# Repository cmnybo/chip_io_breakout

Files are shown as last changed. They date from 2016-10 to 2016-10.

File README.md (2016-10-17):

# C.H.I.P. GPIO Breakout

This is a breakout that attaches to the LCD Adapter board with a 34 pin ribbon cable and IDC connectors.

## Features

* 2 I2C headers
* 6 SPI headers
* 16 pin GPIO header
* 16 pin analog header
* 12 bit 8 channel ADC (MAX11629)
* 12 bit 2 channel DAC (MAX5702)
* Buffered voltage reference output (2.048V & 2.5V)
* External reference voltage input (1.24V - 3.3V)
* Filtered analog power supply.

The original design files for this board were created in [KiCAD](http://kicad-pcb.org/). <br/>
There are PDF copies of the schematic, PCB layout, and bill of materials in the "pdf" directory.<br/>
The "gerber" directory contains all of the files needed to have some boards made.<br/>
The device tree overlay and example python program are in the "source" directory.

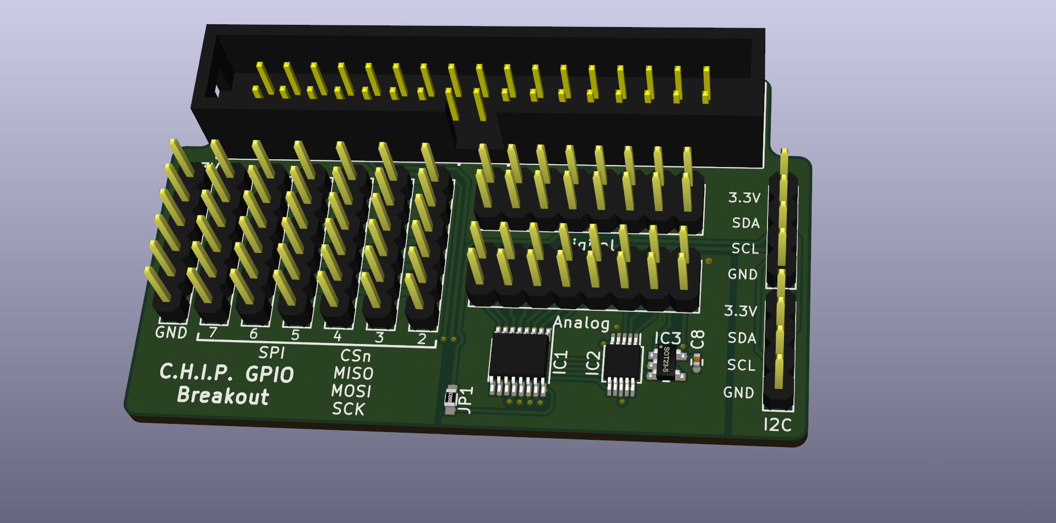
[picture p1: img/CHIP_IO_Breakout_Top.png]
3D Rendering of the breakout board


## Pinouts
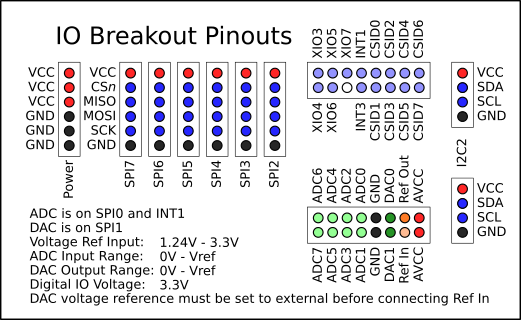
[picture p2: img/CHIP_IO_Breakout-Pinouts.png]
IO Breakout Pinouts Pinouts


## License
**This project is open source hardware.**

The hardware design files are licensed under a [Creative Commons Attribution-ShareAlike](https://creativecommons.org/licenses/by-sa/3.0) license.


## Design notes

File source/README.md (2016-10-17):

# C.H.I.P. GPIO Breakout Python Libraries & Example Program

## Files

<table>
  <tr><th>File</th><th>Description</th></tr>
  <tr><td>spiLib.py</td><td>SPI multiplexer library</td></tr>
  <tr><td>max5702.py</td><td>MAX5702 12 Bit 2 Channel DAC Library</td></tr>
  <tr><td>max11629.py</td><td>MAX11629 12 Bit 8 Channel ADC Library</td></tr>
  <tr><td>io_breakout.py</td><td>A graphical interface for controlling the ADC and DAC</td></tr>
  <tr><td>sine.py</td><td>A script that generates a sine wave on DAC_0 as fast as possible</td></tr>
  <tr><td>interface.glade</td><td>The UI for io_breakout.py</td></tr>
  <tr><td>spi2.dts</td><td>The device tree overlay source for SPI</td></tr>
  <tr><td>spi2.dtbo</td><td>The compiled device tree overlay for SPI</td></tr>
</table>

## The Example Program
The program will read the ADC and display the voltage of all channels 10 times per second when in run mode.<br/>
Clicking the single button will read all channels once.<br/>
The DAC outputs will update immediatly when the values are changed. Enter a value between 0 and 4095 in the input and press enter to apply. Using the up/down arrows will apply it immediatly.<br/>
The voltage reference can be set to 2.048V or 2.5V. This sets the maximum input voltage of the ADC and the maximum output voltage of the DAC.<br/>
If the external reference is selected, you can apply between 1.24V and 3.3V to the Ref In pin. Enter the voltage of the external reference in the numeric input so the ADC and DAC voltages are displayed correctly.
To run this program, you need to install [spidev](https://pypi.python.org/pypi/spidev) and [CHIP_IO](https://github.com/xtacocorex/CHIP_IO).<br/>
The spi2 device tree overlay must be loaded as well as the spidev kernel module. The program must be run as root in order to control the SPI and GPIO.

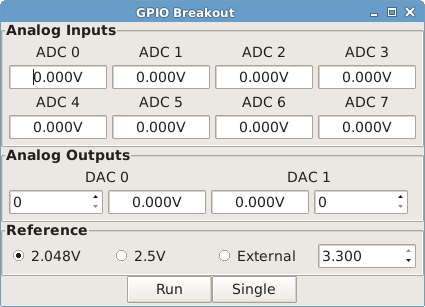
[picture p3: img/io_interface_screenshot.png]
screenshot of the example program


## Library Usage
The spidev and CHIP_IO python libraries must be installed, the spi device tree overlay and spidev module must be loaded, and python must be run as root for this to work.

Import libraries</br>
`import spiLib, max5702, max11629, time`

Open SPI device</br>
`spi = spiLib.SPI(32766, 0)`</br>
`spi.open()`

Create instance of ADC and DAC</br>
`adc = max11629.MAX11629(spi, 0)`</br>
`dac = max5702.MAX5702(spi, 1)`

Configure voltage references</br>
`adc.vRef(False) # disable internal ADC reference`</br>
`dac.vRef(True, dac.REF_20) # enable internal DAC 2.048V reference`

Write to the DAC. Maximum value is 4095.</br>
`dac.write(dac.DAC_0, 1024) # set channel 0 to 0.512V`</br>
`dac.write(dac.DAC_1, 2048) # set channel 1 to 1.024V`

Perform an ADC conversion</br>
`adc.convert(0) # start conversion on channel 0`</br>
`data = adc.read(1,False) # read one entry from ADC FIFO`</br>
`print (((data[0] << 8) | data[1]) & 0x0FFF) # print the ADC reading`

Perform an ADC scan</br>
`adc.scan() # starts a conversion on channels 0-7. takes about 30µs`</br>
`data = adc.read(8,False) # read 8 entries from ADC FIFO`</br>
`time.sleep(0.0001) # give it some time to finish the conversions`</br>
`# print all 8 channels`</br>
`for i in range(0, 16, 2): print (((data[i] << 8) | data[i+1]) & 0x0FFF)`

Clean up. You must run these before exiting your program to free up the SPI and GPIO pins.</br>
`spi.close()`</br>
`spi.cleanup()`</br>

## License

This program is free software; you can redistribute it and/or modify</br>
it under the terms of the GNU General Public License as published by</br>
the Free Software Foundation; either version 2 of the License, or</br>
(at your option) any later version.</br>

This program is distributed in the hope that it will be useful,</br>
but WITHOUT ANY WARRANTY; without even the implied warranty of</br>
MERCHANTABILITY or FITNESS FOR A PARTICULAR PURPOSE.  See the</br>
GNU General Public License for more details.</br>

You should have received a copy of the GNU General Public License</br>
along with this program; if not, write to the Free Software</br>
Foundation, Inc., 51 Franklin Street, Fifth Floor, Boston,</br>
MA 02110-1301, USA.</br>

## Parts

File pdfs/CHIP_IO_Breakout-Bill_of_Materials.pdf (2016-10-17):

Bill of Materials

Page 1

Reference | Value | Manufacturer | Package | DigiKey | Quantity Notes
IC1 | MAX11629 | Maxim Integrated | 16-SSOP (3.90mm) MAX11629EEE+-ND | 1
IC2 | MAX5702 | Maxim Integrated | 10-MSOP (3.00mm) MAX5702AAUB+-ND | 1
IC3 | MCP6L01 | Microchip | SOT-23-5 | MCP6L01T-E/OTCT-ND | 1
C1, C6 | 0.1µF | Samsung | 0402 | 1276-1001-1-ND | 2
C2, C5 | 1µF | Samsung | 0603 | 1276-6524-1-ND | 2
C3, C4 | 10µF | Samsung | 0805 | 1276-6457-1-ND | 2
C7 – C9 | 0.1µF | Samsung | 0603 | 1276-1006-1-ND | 3
L1 | 100µH | Taiyo Yuden | 1210 | 587-1628-1-ND | 1
P1, P2 | 8x2 Pin | Harwin Inc. | | 952-2553-ND | 2 8x2 Male Pin Header
P3, P5 | 4x1 Pin | Harwin Inc. | | 952-2265-ND | 2 4x1 Male Pin Header
P7 – P12, P14 6x1 Pin | Harwin Inc. | 952-2269-ND | 7 6x1 Male Pin Header
P14 | 17x2 Pin | On Shore Technology Inc. | | ED10528-ND | 1 17x2 Shrouded Male Header

Notes
Capacitors can be substituted as long as the package, voltage, and capacitance is the same. Use X5R or X7R dielectric.
Resistors can be substituted as long as the package and resistance are the same.
Cheap pin headers from eBay will work fine if you want to save some money. DigiKey is expensive for pin headers.

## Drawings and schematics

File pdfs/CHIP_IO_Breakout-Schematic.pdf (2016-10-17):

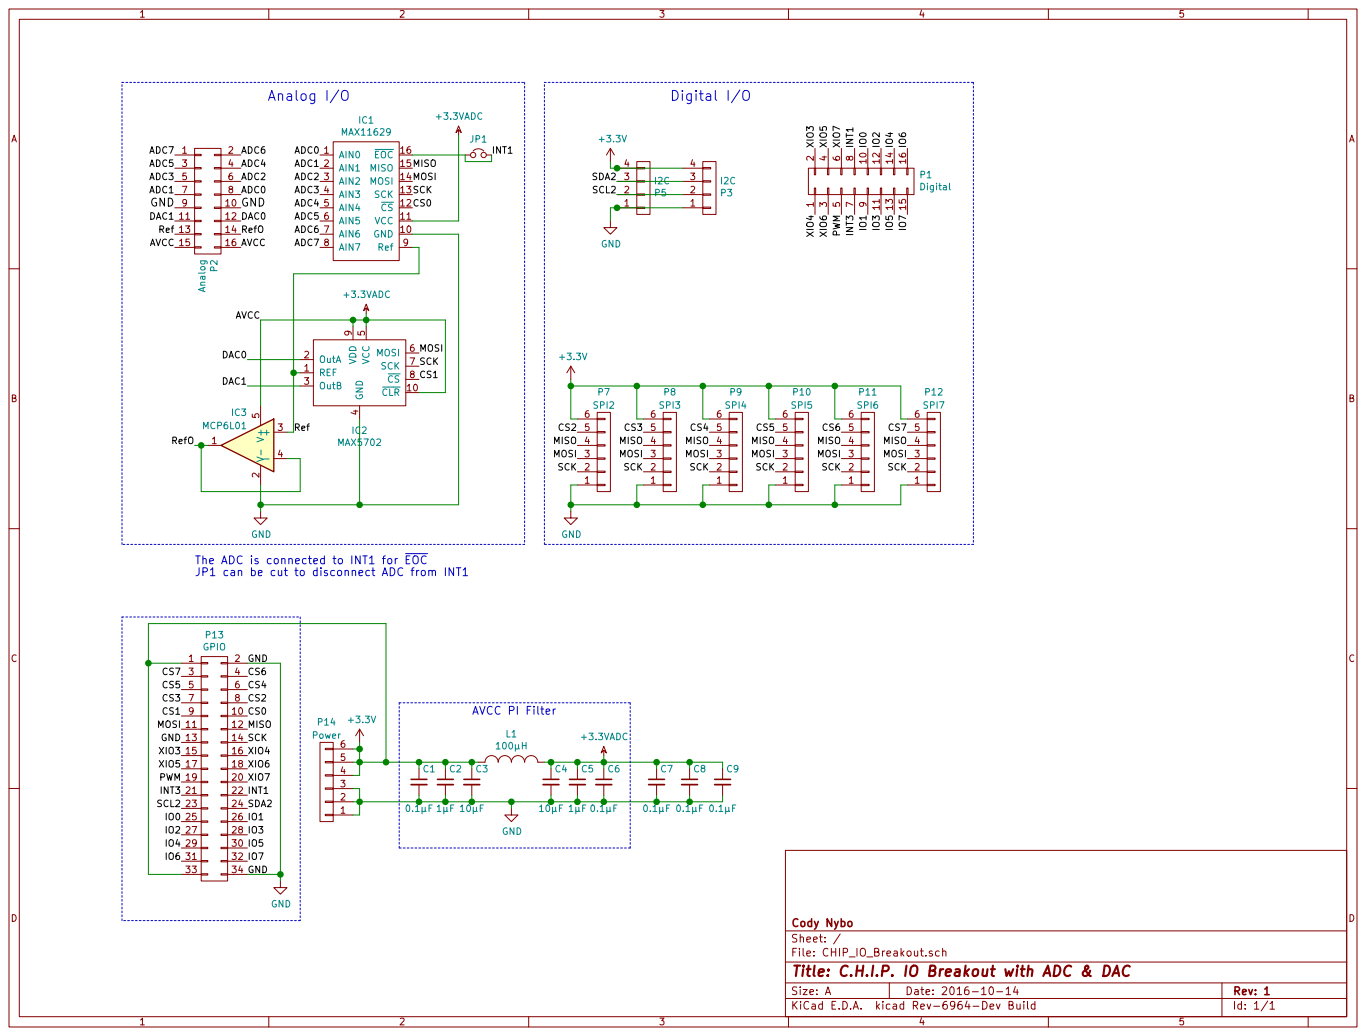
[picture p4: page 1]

I2C The ADC is connected to INT1 for EOC
RefO GND

5 MOSI 6 SCK 7 CS 8 VDD

File: CHIP_IO_Breakout.sch Sheet: / Cody Nybo

Id: 1/1 Title: C.H.I.P. IO Breakout with ADC & DAC

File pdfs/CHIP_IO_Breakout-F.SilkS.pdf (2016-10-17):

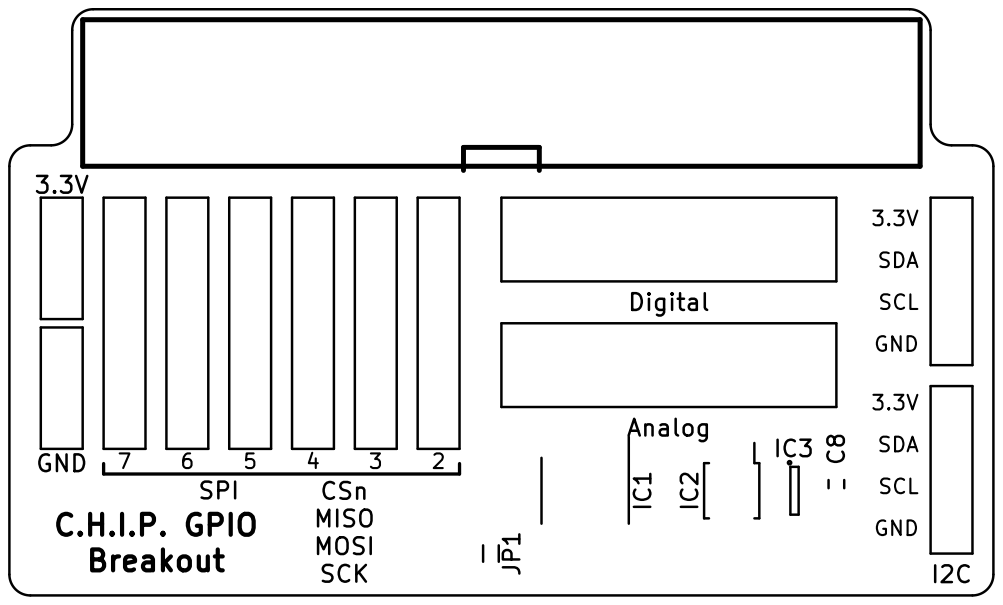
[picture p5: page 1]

I2C GND
File: CHIP_IO_Breakout.kicad_pcb Sheet: Cody Nybo C.H.I.P. GPIO

Id: 1/1 Title: C.H.I.P. IO Breakout with ADC & DAC

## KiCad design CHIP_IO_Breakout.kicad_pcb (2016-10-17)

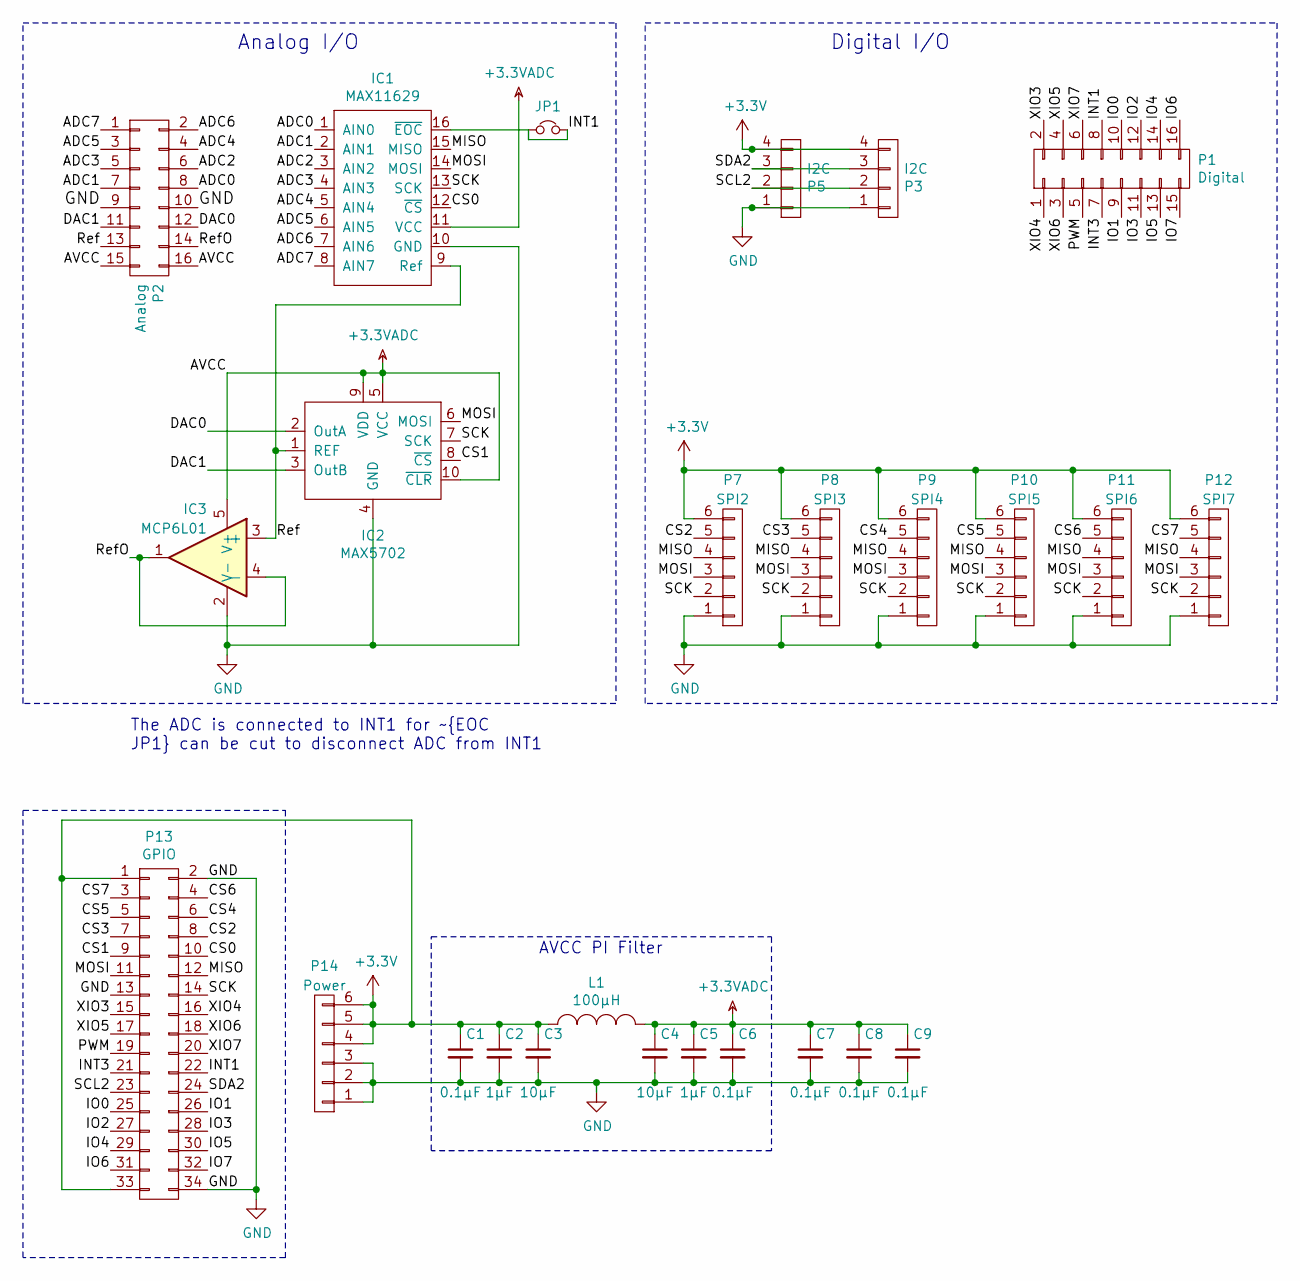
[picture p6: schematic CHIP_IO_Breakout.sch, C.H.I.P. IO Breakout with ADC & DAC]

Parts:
C1, C6: 0.1µF; C_0402; Voltage 16V; Tolerance 10%; DigiKey 1276-1001-1-ND
C2, C5: 1µF; C_0603; Voltage 16V; Tolerance 20%; DigiKey 1276-6524-1-ND
C3, C4: 10µF; C_0805; Voltage 6.3V; Tolerance 10%; DigiKey 1276-6457-1-ND
C7, C8, C9: 0.1µF; C_0603; Voltage 25V; Tolerance 10%; DigiKey 1276-1006-1-ND
IC1: MAX11629; SSOP-16_3.9x4.9mm_Pitch0.635mm; DigiKey MAX11629EEE+-ND
IC2: MAX5702; MSOP-10_3x3mm_Pitch0.5mm; DigiKey MAX5702AAUB+-ND
IC3: MCP6L01; SOT-23-5; DigiKey MCP6L01T-E/OTCT-ND
JP1: Jumper_NC_Small; Pin_Header_Straight_1x02
L1: 100µH; C_1210; Tolerance 20%; DigiKey 587-1628-1-ND
P1: Digital; Pin_Header_Straight_2x08
P2: Analog; Pin_Header_Straight_2x08
P3, P5: I2C; Pin_Header_Straight_1x04
P7: SPI2; Pin_Header_Straight_1x06
P8: SPI3; Pin_Header_Straight_1x06
P9: SPI4; Pin_Header_Straight_1x06
P10: SPI5; Pin_Header_Straight_1x06
P11: SPI6; Pin_Header_Straight_1x06
P12: SPI7; Pin_Header_Straight_1x06
P13: GPIO; vasch_strip_17x2
P14: Power; Pin_Header_Straight_1x06

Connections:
+3.3VADC: C4.1, C5.1, C6.1, C7.1, C8.1, C9.1, IC1.11 (VCC), IC2.5 (VCC), IC2.9 (VDD), IC2.10 (~CLR), IC3.5 (V+), L1.2, P2.15, P2.16
+3V3: C1.1, C2.1, C3.1, L1.1, P3.4, P5.4, P7.6, P8.6, P9.6, P10.6, P11.6, P12.6, P13.1, P13.33, P14.4, P14.5, P14.6
/ADC0: IC1.1 (AIN0), P2.8
/ADC1: IC1.2 (AIN1), P2.7
/ADC2: IC1.3 (AIN2), P2.6
/ADC3: IC1.4 (AIN3), P2.5
/ADC4: IC1.5 (AIN4), P2.4
/ADC5: IC1.6 (AIN5), P2.3
/ADC6: IC1.7 (AIN6), P2.2
/ADC7: IC1.8 (AIN7), P2.1
/CS0: IC1.12 (~CS), P13.10
/CS1: IC2.8 (~CS), P13.9
/CS2: P7.5, P13.8
/CS3: P8.5, P13.7
/CS4: P9.5, P13.6
/CS5: P10.5, P13.5
/CS6: P11.5, P13.4
/CS7: P12.5, P13.3
/DAC0: IC2.2 (OutA), P2.12
/DAC1: IC2.3 (OutB), P2.11
/INT1: IC1.16 (~EOC), JP1.1, JP1.2, P1.8, P13.22
/INT3: P1.7, P13.21
/IO0: P1.10, P13.25
/IO1: P1.9, P13.26
/IO2: P1.12, P13.27
/IO3: P1.11, P13.28
/IO4: P1.14, P13.29
/IO5: P1.13, P13.30
/IO6: P1.16, P13.31
/IO7: P1.15, P13.32
/MISO: IC1.15 (MISO), P7.4, P8.4, P9.4, P10.4, P11.4, P12.4, P13.12
/MOSI: IC1.14 (MOSI), IC2.6 (MOSI), P7.3, P8.3, P9.3, P10.3, P11.3, P12.3, P13.11
/PWM: P1.5, P13.19
/Ref: IC1.9 (Ref), IC2.1 (REF), IC3.3 (+), P2.13
/RefO: IC3.1, IC3.4 (-), P2.14
/SCK: IC1.13 (SCK), IC2.7 (SCK), P7.2, P8.2, P9.2, P10.2, P11.2, P12.2, P13.14
/SCL2: P3.2, P5.2, P13.23
/SDA2: P3.3, P5.3, P13.24
/XIO3: P1.2, P13.15
/XIO4: P1.1, P13.16
/XIO5: P1.4, P13.17
/XIO6: P1.3, P13.18
/XIO7: P1.6, P13.20
GND: C1.2, C2.2, C3.2, C4.2, C5.2, C6.2, C7.2, C8.2, C9.2, IC1.10 (GND), IC2.4 (GND), IC3.2 (V-), P2.9, P2.10, P3.1, P5.1, P7.1, P8.1, P9.1, P10.1, P11.1, P12.1, P13.2, P13.13, P13.34, P14.1, P14.2, P14.3

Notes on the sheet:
Analog I/O
Digital I/O
The ADC is connected to INT1 for ~EOC JP1 can be cut to disconnect ADC from INT1
AVCC PI Filter

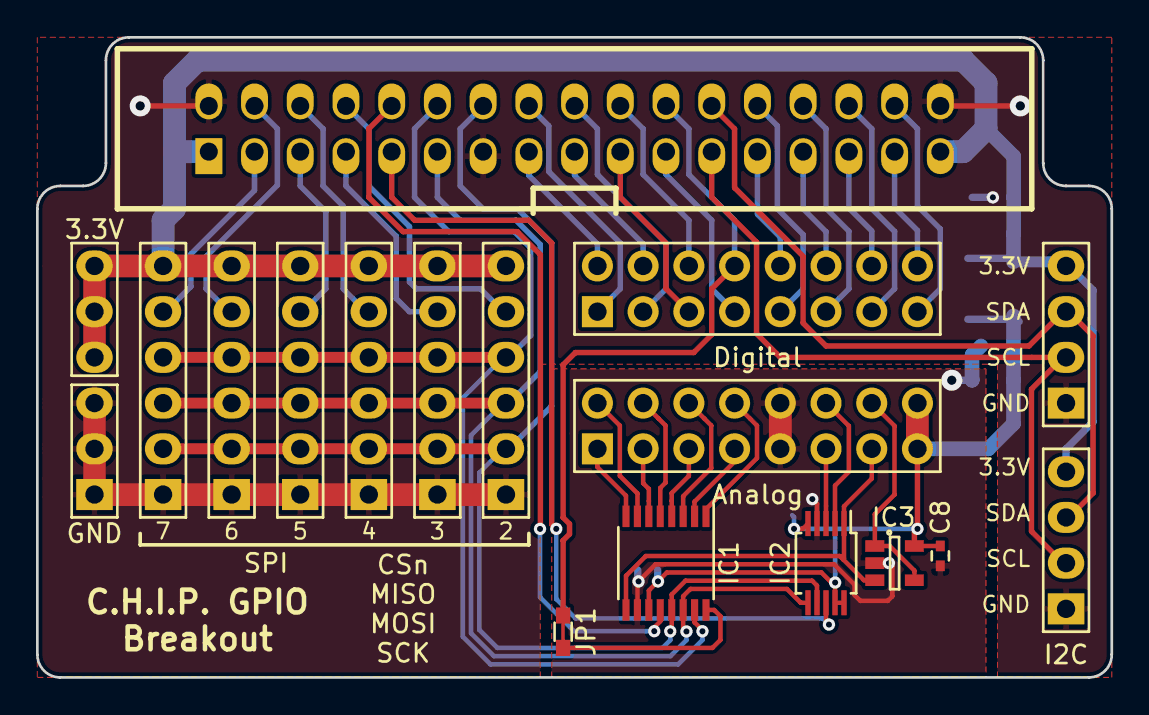
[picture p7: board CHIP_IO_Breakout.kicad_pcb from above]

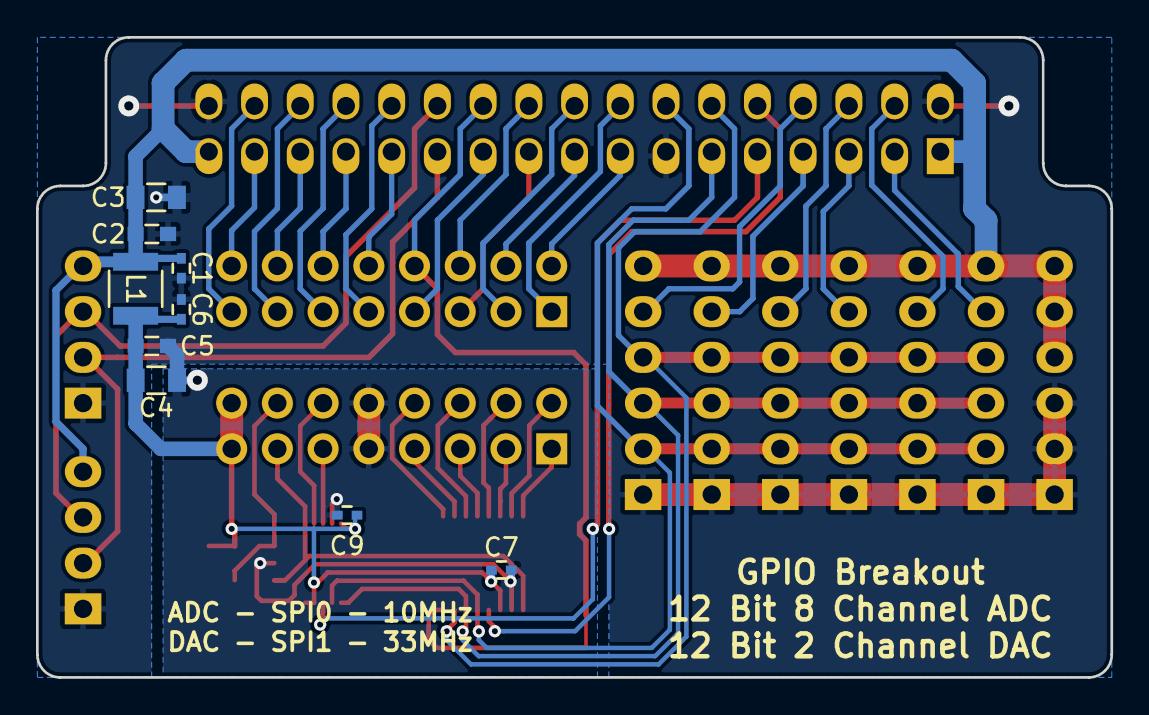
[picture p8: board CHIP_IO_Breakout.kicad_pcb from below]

Board: 2 copper layers, 59.7 x 35.6 mm, 26 parts (9 on the bottom side), 44 nets.

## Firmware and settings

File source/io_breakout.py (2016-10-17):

#!/usr/bin/python

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
# This program requires spiLib.py, max5702.py, max11629.py, & interface.glade
# This program requires spidev and CHIP_IO to be installed
# https://pypi.python.org/pypi/spidev
# https://github.com/xtacocorex/CHIP_IO

import gtk, gobject, threading, os, sys, time
import spiLib, max5702, max11629
import CHIP_IO.GPIO as GPIO

class GPIO_Breakout(object):
  def __init__(self):
    gobject.threads_init()
    
    # setup gui
    builder = gtk.Builder()
    builder.add_from_file("interface.glade")
    builder.connect_signals(self)
    # Windows
    self.mainWindow = builder.get_object("mainWindow")
    self.mainWindow.connect("destroy", gtk.main_quit)
    # Buttons
    self.btnRun = builder.get_object("btnRun")
    self.btnSingle = builder.get_object("btnSingle")
    # Radio buttons
    self.radRef = [
      builder.get_object("radRef0"),
      builder.get_object("radRef1"),
      builder.get_object("radRef2")     
    ]    
    # Text boxes
    self.txtADC = [
      builder.get_object("txtADC0"),
      builder.get_object("txtADC1"),
      builder.get_object("txtADC2"),
      builder.get_object("txtADC3"),
      builder.get_object("txtADC4"),
      builder.get_object("txtADC5"),
      builder.get_object("txtADC6"),
      builder.get_object("txtADC7")
    ]
    
    self.txtDAC = [
      builder.get_object("txtDAC0"),
      builder.get_object("txtDAC1")  
    ]
    # Number inputs
    self.numDAC0    = builder.get_object("numDAC0") 
    self.numDAC1    = builder.get_object("numDAC1") 
    self.numExtRef  = builder.get_object("numExtRef") 
    # Adjustments
    self.adjDAC0    = builder.get_object("adjDAC0") 
    self.adjDAC1    = builder.get_object("adjDAC1") 
    self.adjExtRef  = builder.get_object("adjExtRef") 
    
    self.ref = 2.048
    self.extRef = False
    self.run = False
    self.adcVals = [0,0,0,0,0,0,0,0]
    self.dacVals = [0,0]
    
    # ADC read interval: 100ms
    self.adcInt  = 0.1
    
    self.initHardware()
  
  # starts / stops adc updating
  def on_btnRun_toggled(self, button):
    self.run = button.get_active()
    
    if (self.run):
      button.set_label("Stop")
      self.adcTimer = threading.Timer(self.adcInt, self.readADC)
      self.adcTimer.start()
    else:
      button.set_label("Run")
      self.adcTimer.cancel()
  
  # Perform ADC Scan  
  def on_btnSingle_clicked(self, button):
    print "Scanning ADC"
    
    adc.read(16, True) # Empty FIFO first
    adc.scan()
    time.sleep(0.01)    
    # Read data from ADC
    adcData = adc.read(8, False)
    
    # Proccess data and store
    data = []
    for i in range(0,16,2):
      data.append(((adcData[i] << 8) | adcData[i+1]) & 0x0FFF)
    
    self.adcVals = data
    
    self.updateVoltages()
    print "Done Scanning ADC"
  
  # voltage reference changed
  def on_radRef0_toggled(self, button):
    if (button == self.radRef[0]):
      self.ref = 2.048
      self.extRef = False
      dac.vRef(True, dac.REF_20)
    
    elif (button == self.radRef[1]):
      self.ref = 2.5
      self.extRef = False
      dac.vRef(True, dac.REF_25)
      
    elif (button == self.radRef[2]):
      self.ref = self.adjExtRef.get_value()
      self.extRef = True
      dac.vRef(True, dac.REF_EXT)
    
    self.updateVoltages()
  
  # dac0 changed
  def on_numDAC0_value_changed(self, num):
    self.dacVals[0] = self.adjDAC0.get_value()
    self.updateVoltages()
    
    dac.write(dac.DAC_0, self.dacVals[0])
  
  # dac1 changed
  def on_numDAC1_value_changed(self, num):
    self.dacVals[1] = self.adjDAC1.get_value()
    self.updateVoltages()
    
    dac.write(dac.DAC_1, self.dacVals[1])
  
  # external reference voltage changed
  def on_numExtRef_value_changed(self, num):
    if (self.extRef):
      self.ref = self.adjExtRef.get_value()
      self.updateVoltages()
  
  # calculates voltage from adc / dac value
  def calcVoltage(self, value, maxVal,  ref):
    return (ref / maxVal) * value
  
  # updates voltage textboxes
  def updateVoltages(self):
    # ADC voltages
    for i in range(0,8):
      voltage = self.calcVoltage(self.adcVals[i], 4096, self.ref)
      self.txtADC[i].set_text('{:5.3f}V'.format(voltage))
    
    # DAC voltages
    for i in range(0,2):
      voltage = self.calcVoltage(self.dacVals[i], 4096, self.ref)
      self.txtDAC[i].set_text('{:5.3f}V'.format(voltage))

  # reads adc and starts display update
  def readADC(self):
    def update():
      gtk.threads_enter()
      try:
        self.updateVoltages()
        
      finally:
        gtk.threads_leave()
    
    # Perform ADC Scan
    adc.read(16, True) # Empty FIFO first
    adc.scan()
    time.sleep(0.001) 
    # Read data from ADC
    adcData = adc.read(8, False)
    
    # Proccess data and store
    data = []
    for i in range(0,16,2):
      data.append(((adcData[i] << 8) | adcData[i+1]) & 0x0FFF)
    self.adcVals = data
    
    # Update text boxes
    gobject.idle_add(update)
    
    # Restart timer
    self.adcTimer = threading.Timer(self.adcInt, self.readADC)
    self.adcTimer.start()
  
  # configures voltage references
  def initHardware(self):
    dac.vRef(True, dac.REF_20)
    adc.vRef(False)
  
if __name__ == "__main__":
  os.chdir(sys.path[0])
  
  # open spi
  spi = spiLib.SPI(32766, 0)
  spi.open()
  
  # initilize DAC and ADC
  dac = max5702.MAX5702(spi, 1)
  adc = max11629.MAX11629(spi, 0)
  adc.read(16, True)    # clear ADC FIFO
  
  # show main window and start main thread
  io = GPIO_Breakout()
  io.mainWindow.show()
  gtk.main()
  
  # close spi on exit
  spi.close()
  spi.cleanup()

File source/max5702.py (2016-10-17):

# -*- coding: utf-8 -*-

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
import spiLib

class MAX5702(object):
  DAC_0         = 0x00  # Specify DAC 0
  DAC_1         = 0x01  # Specify DAC 1
  DAC_ALL       = 0x08  # Specify all DACs
  REF_EXT       = 0x00  # Use external reference
  REF_25        = 0x01  # Use internal 2.5V ref
  REF_20        = 0x02  # Use internal 2.048V ref
  REF_41        = 0x03  # Use internal 4.096V ref (Doesn't work with 3.3V supply)
  PWR_ON        = 0x00  # Power on
  PWR_OFF       = 0x03  # Power off Hi-Z output
  PWR_OFF_1K    = 0x01  # Power off 1K Pulldown
  PWR_OFF_100K  = 0x02  # Power off 100K Pulldown
  
  def __init__(self, spi, ch):
    self.spi = spi
    self.channel = ch
    self.configSPI()
    self.spi.write([0x51, 0x00, 0x00])   # Reset DAC
    self.spi.write([0x76, 0x00, 0x00])   # Set reference to 2.048V
    self.spi.write([0x40, 0x03, 0x00])   # Power up both DACs

  def configSPI(self):
    # configure spi settings
    # Supports SPI mode 1, MSB first, 33MHz Max
    self.spi.setChannel(self.channel)
    self.spi.config(5000, 0x1, False)
  
  def code(self, dac, value):
    # Writes to code register on selected dac
    if (int(value) > 4095): value = 4095
    if (int(value) < 0):    value = 0
    
    cmd  = 0x00 | (int(dac) & 0x0F)
    lVal = (int(val) << 4) & 0xFF
    hVal = (int(val) >> 4) & 0xFF
    
    self.configSPI()
    self.spi.write([cmd, hVal, lVal])
  
  def load(self, dac):
    # Loads code register on selected dac
    cmd  = 0x10 | (int(dac) & 0x0F)
    
    self.configSPI()
    self.spi.write([cmd, 0x00, 0x00])
  
  def write(self, dac, val):
    # Writes code register and loads on selected dac
    if (int(val) > 4095): val = 4095
    if (int(val) < 0):    val = 0
    
    cmd  = 0x30 | (int(dac) & 0x0F)
    lVal = (int(val) << 4) & 0xFF
    hVal = (int(val) >> 4) & 0xFF
    
    self.configSPI()
    self.spi.write([cmd, hVal, lVal])
    
  def clear(self):
    # Clears all code & dac registers
    self.configSPI()
    self.spi.write([0x50, 0x00, 0x00])
    
  def reset(self):
    # Resets all registers
    self.configSPI()
    self.spi.write([0x51, 0x00, 0x00])
    
  def vRef(self, enable, level):
    # enables reference and sets level
    en = 0x04 if (bool(enable)) else 0x00
    cmd  = 0x70 | en | (int(level) & 0x03)
    
    self.configSPI()
    self.spi.write([cmd, 0x00, 0x00])
  
  def power(self, dac, pwr):
    # Sets power mode for the dacs
    cmd = 0x40 | (int(dac) & 0x03)
    dacs = {0x0:0x1, 0x1:0x2, 0x8:0x3}.get(int(pwr), 0x3)
    
    self.configSPI()
    self.spi.write([cmd, dacs, 0x00])
